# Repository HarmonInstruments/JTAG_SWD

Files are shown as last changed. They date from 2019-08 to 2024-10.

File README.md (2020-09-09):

# JTAG_SWD

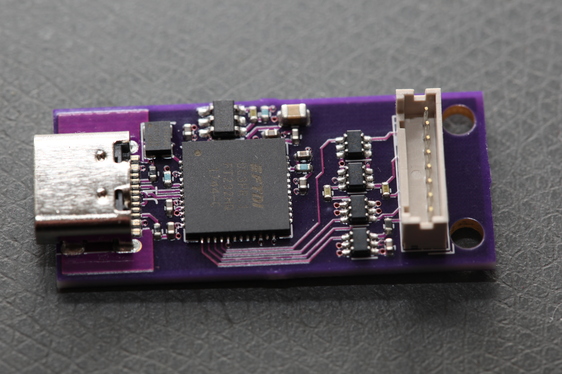
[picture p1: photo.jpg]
photo of PCB


## JTAG

Hirose DF3A-6P-2DS header

## Adapter Cables

###

Hirose DF3-6EP-2C 6 pin inline header

TC2030-MCP
TC2030-MCP-NL

## Pinout

|Pin |JTAG | Serial Wire | AVR |
|----|-----|---|-----|
| 1  | VCC | VCC | VCC |
| 2  | TCK | SWCLK | SCK |
| 3  | GND | GND | GND |
| 4  | TDO | SWDIO | MISO |
| 5  | NC  | jumper to 6 | NC |
| 6  | NC  | jumper to 5 | NC |
| 7  | TDI | SWDIO | MOSI |
| 8  | TMS | NC | RST |

## OpenOCD config for ECP5-12

```
interface ftdi
ftdi_channel 0
ftdi_vid_pid 0x0403 0x6014
ftdi_layout_init 0x0058 0x00fb
ftdi_layout_signal nTRST -data 0x0010
ftdi_layout_signal nSRST -oe 0x0020
adapter_khz 10000

telnet_port 4444
gdb_port 3333
transport select jtag
reset_config none

jtag newtap lfe5 tap -expected-id 0x21111043 -irlen 8 -irmask 0xFF -ircapture 0x5
init
scan_chain
svf -tap lfe5.tap -quiet -progress build/display_fpga.svf
shutdown
```

## OpenOCD config for XC7A15T
```
interface ftdi
ftdi_channel 0
ftdi_vid_pid 0x0403 0x6014
ftdi_layout_init 0x0058 0x00fb
ftdi_layout_signal nTRST -data 0x0010
ftdi_layout_signal nSRST -oe 0x0020
telnet_port 4444
gdb_port 3333
transport select jtag
reset_config none
jtag newtap artix7 tap -irlen 6 -ignore-version -expected-id 0x0362E093
pld device virtex2 artix7.tap
adapter_khz 10000
adapter_nsrst_delay 200
init
pld load 0 top.bit
virtex2 read_stat 0
shutdown
```

## OpenOCD for SWD STM32F4

swd.cfg
```
source [find openocd.cfg]
flash info 0
flash write_image erase digital.elf
reset run
exit
```

openocd.cfg
```
interface ftdi
transport select swd
ftdi_channel 0
ftdi_vid_pid 0x0403 0x6014
ftdi_layout_init 0x0058 0x00fb
ftdi_layout_signal SWD_EN -data 0x0200
adapter_khz 1000
telnet_port 4444
gdb_port 3333
reset_config none
source [find target/stm32f4x.cfg]
init
reset halt
sleep 100
```

## AVRDude

```
avrdude -c c232hm -P USB -p m32u4 -v -b 500000
```

Higher baud rates failed.

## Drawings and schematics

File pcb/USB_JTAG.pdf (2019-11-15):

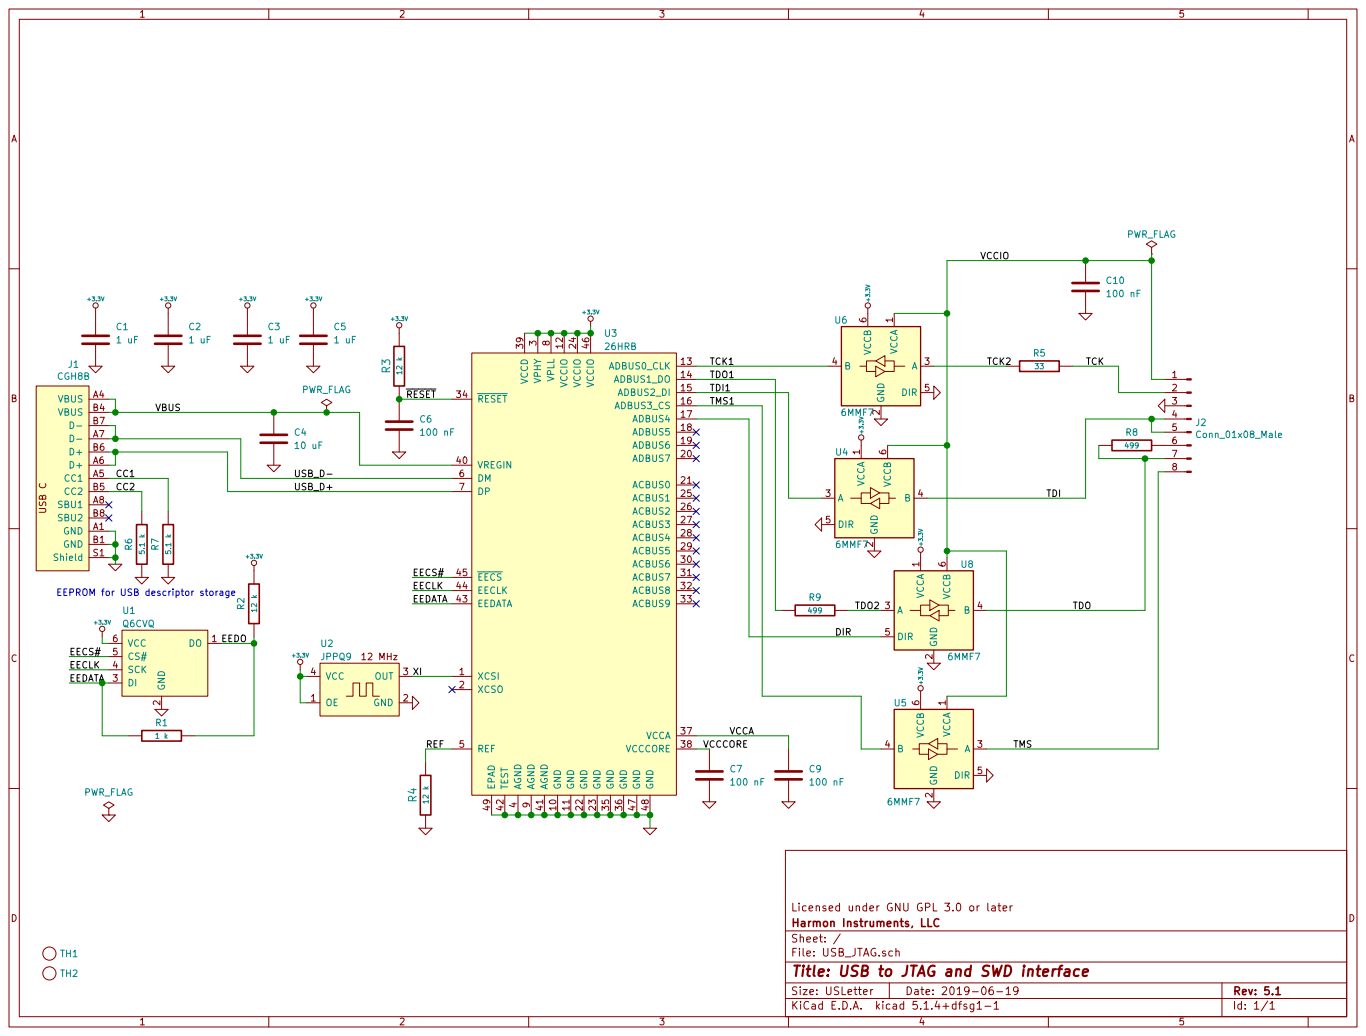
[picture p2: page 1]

3 ACBUS6 30 ACBUS7 31 ACBUS8 32 ACBUS9 33 RESET 34 GND 35 GND 36 VCCA 37 VCCCORE 38 VCCD 39 AGND

4 VREGIN 40 AGND 41 TEST 42 EEDATA 43 EECLK 44 EECS 45 VCCIO 46 GND 47 GND 48 EPAD 49 REF 5 DM 6 DP 7 VPLL

EEPROM for USB descriptor storage

2 DI 3 SCK 4 CS# 5 VCC 6 U1 Q6CVQ

File: USB_JTAG.sch Sheet: / Harmon Instruments, LLC

Id: 1/1 Title: USB to JTAG and SWD interface

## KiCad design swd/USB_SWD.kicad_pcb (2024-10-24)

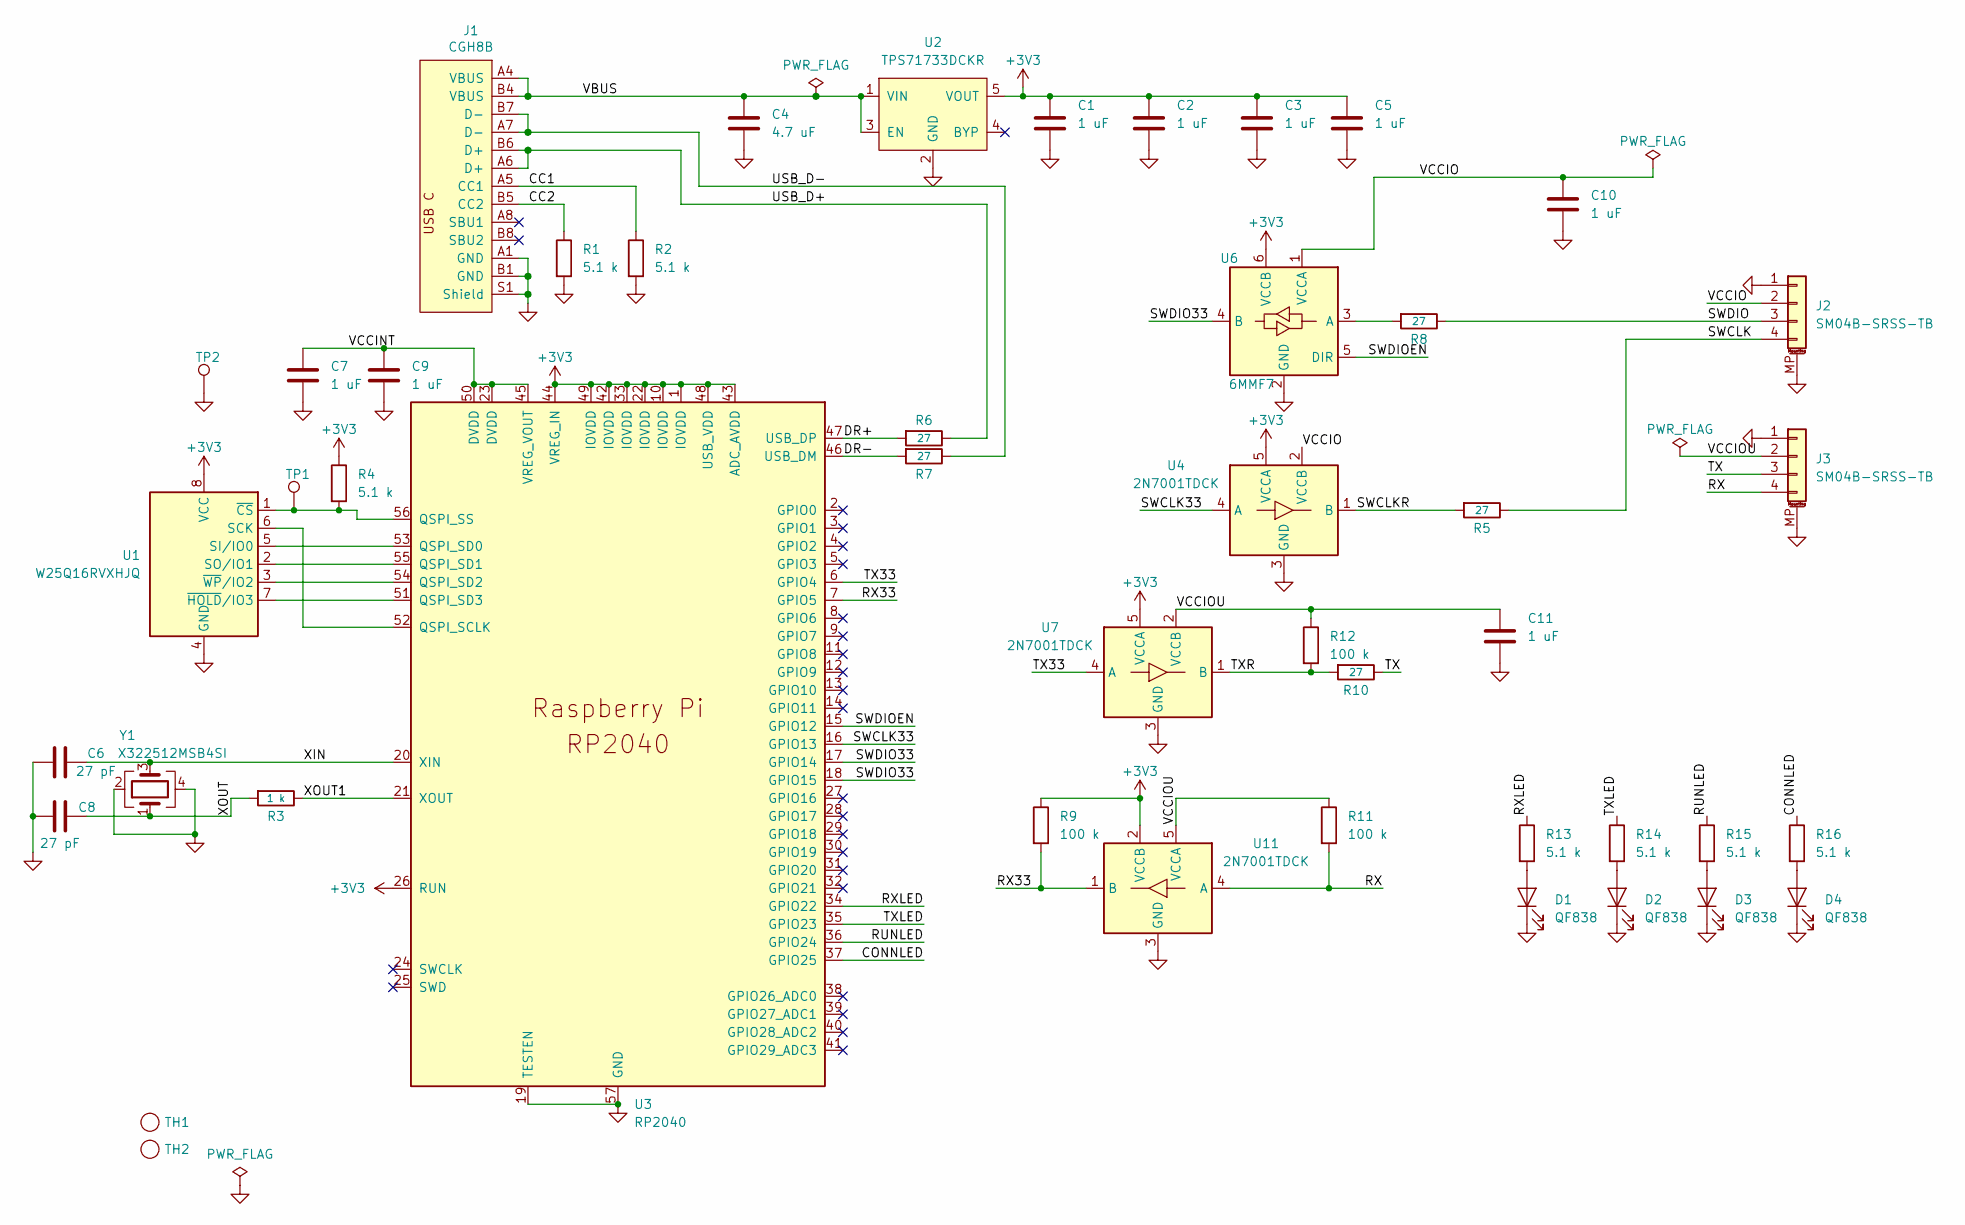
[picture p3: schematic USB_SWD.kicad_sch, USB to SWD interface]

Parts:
C1, C2, C3, C5, C7, C9, C10, C11: 1 uF; C_0402_1005Metric
C4: 4.7 uF; C_0603_1608Metric
C6, C8: 27 pF; C_0402_1005Metric
D1, D2, D3, D4: QF838; LED_0603_1608Metric
J1: CGH8B; USB_C_Receptacle_HRO_TYPE-C-31-M-12
J2, J3: SM04B-SRSS-TB; JST_SH_SM04B-SRSS-TB_1x04-1MP_P1.00mm_Horizontal
R1, R2, R4, R13, R14, R15, R16: 5.1 k; R_0402_1005Metric
R3: 1 k; R_0402_1005Metric
R5, R6, R7, R8, R10: 27; R_0402_1005Metric
R9, R11, R12: 100 k; R_0402_1005Metric
TH1, TH2: tooling_hole; tooling_hole_2.55
TP1, TP2: TestPoint; TestPoint_THTPad_1.5x1.5mm_Drill0.7mm
U1: W25Q16RVXHJQ; XSON-8-1EP_3x2mm_P0.5mm_EP0.2x1.6mm
U2: TPS71733DCKR; SOT-353_SC-70-5
U3: RP2040; QFN-56-RP2040
U4, U7, U11: 2N7001TDCK; SOT-353_SC-70-5
U6: 6MMF7; SOT-363_SC-70-6
Y1: X322512MSB4SI; Oscillator_SMD_SeikoEpson_SG8002CE-4Pin_3.2x2.5mm; LCSC C9002

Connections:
+3V3: C1.1, C2.1, C3.1, C5.1, R4.1, R9.1, U1.8 (VCC), U2.5 (VOUT), U3.1 (IOVDD), U3.10 (IOVDD), U3.22 (IOVDD), U3.26 (RUN), U3.33 (IOVDD), U3.42 (IOVDD), U3.43 (ADC_AVDD), U3.44 (VREG_IN), U3.48 (USB_VDD), U3.49 (IOVDD), U4.5 (VCCA), U6.6 (VCCB), U7.5 (VCCA), U11.2 (VCCB)
/CC1: J1.A5 (CC1), R2.1
/CC2: J1.B5 (CC2), R1.1
/CONNLED: R16.1, U3.37 (GPIO25)
/DR+: R6.2, U3.47 (USB_DP)
/DR-: R7.2, U3.46 (USB_DM)
/RUNLED: R15.1, U3.36 (GPIO24)
/RX: J3.4, R11.2, U11.4 (A)
/RX33: R9.2, U3.7 (GPIO5), U11.1 (B)
/RXLED: R13.1, U3.34 (GPIO22)
/SWCLK: J2.4, R5.1
/SWCLK33: U3.16 (GPIO13), U4.4 (A)
/SWCLKR: R5.2, U4.1 (B)
/SWDIO: J2.3, R8.1
/SWDIO33: U3.17 (GPIO14), U3.18 (GPIO15), U6.4 (B)
/SWDIOEN: U3.15 (GPIO12), U6.5 (DIR)
/TX: J3.3, R10.1
/TX33: U3.6 (GPIO4), U7.4 (A)
/TXLED: R14.1, U3.35 (GPIO23)
/TXR: R10.2, R12.2, U7.1 (B)
/USB_D+: J1.A6 (D+), J1.B6 (D+), R6.1
/USB_D-: J1.A7 (D-), J1.B7 (D-), R7.1
/VBUS: C4.1, J1.A4 (VBUS), J1.B4 (VBUS), U2.1 (VIN), U2.3 (EN)
/VCCINT: C7.1, C9.1, U3.23 (DVDD), U3.45 (VREG_VOUT), U3.50 (DVDD)
/VCCIO: C10.1, J2.2, U4.2 (VCCB), U6.1 (VCCA)
/VCCIOU: C11.1, J3.2, R11.1, R12.1, U7.2 (VCCB), U11.5 (VCCA)
/XIN: C6.1, U3.20 (XIN), Y1.3
/XOUT: C8.1, R3.2, Y1.1
/XOUT1: R3.1, U3.21 (XOUT)
GND: C1.2, C2.2, C3.2, C4.2, C5.2, C6.2, C7.2, C8.2, C9.2, C10.2, C11.2, D1.1 (K), D2.1 (K), D3.1 (K), D4.1 (K), J1.A1 (GND), J1.B1 (GND), J1.S1 (Shield), J2.1, J2.MP (MountPin), J3.1, J3.MP (MountPin), R1.2, R2.2, TP2.1, U1.4 (GND), U2.2 (GND), U3.19 (TESTEN), U3.57 (GND), U4.3 (GND), U6.2 (GND), U7.3 (GND), U11.3 (GND), Y1.2, Y1.4
unnamed: D1.2 (A), R13.2
unnamed: D2.2 (A), R14.2
unnamed: D3.2 (A), R15.2
unnamed: D4.2 (A), R16.2
unnamed: U1.6 (SCK), U3.52 (QSPI_SCLK)
unnamed: U1.5 (SI/IO0), U3.53 (QSPI_SD0)
unnamed: U1.2 (SO/IO1), U3.55 (QSPI_SD1)
unnamed: R4.2, TP1.1, U1.1 (~CS), U3.56 (QSPI_SS)
unnamed: U1.7 (~HOLD/IO3), U3.51 (QSPI_SD3)
unnamed: U1.3 (~WP/IO2), U3.54 (QSPI_SD2)
unnamed: R8.2, U6.3 (A)

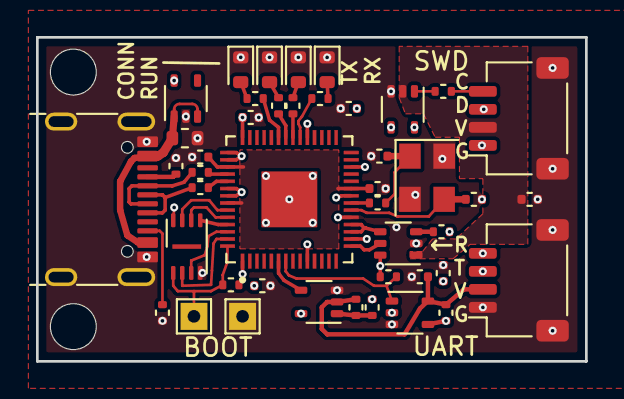
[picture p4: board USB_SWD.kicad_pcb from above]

Board: 6 copper layers, 30.5 x 18.0 mm, 46 parts (0 on the bottom side), 41 nets.

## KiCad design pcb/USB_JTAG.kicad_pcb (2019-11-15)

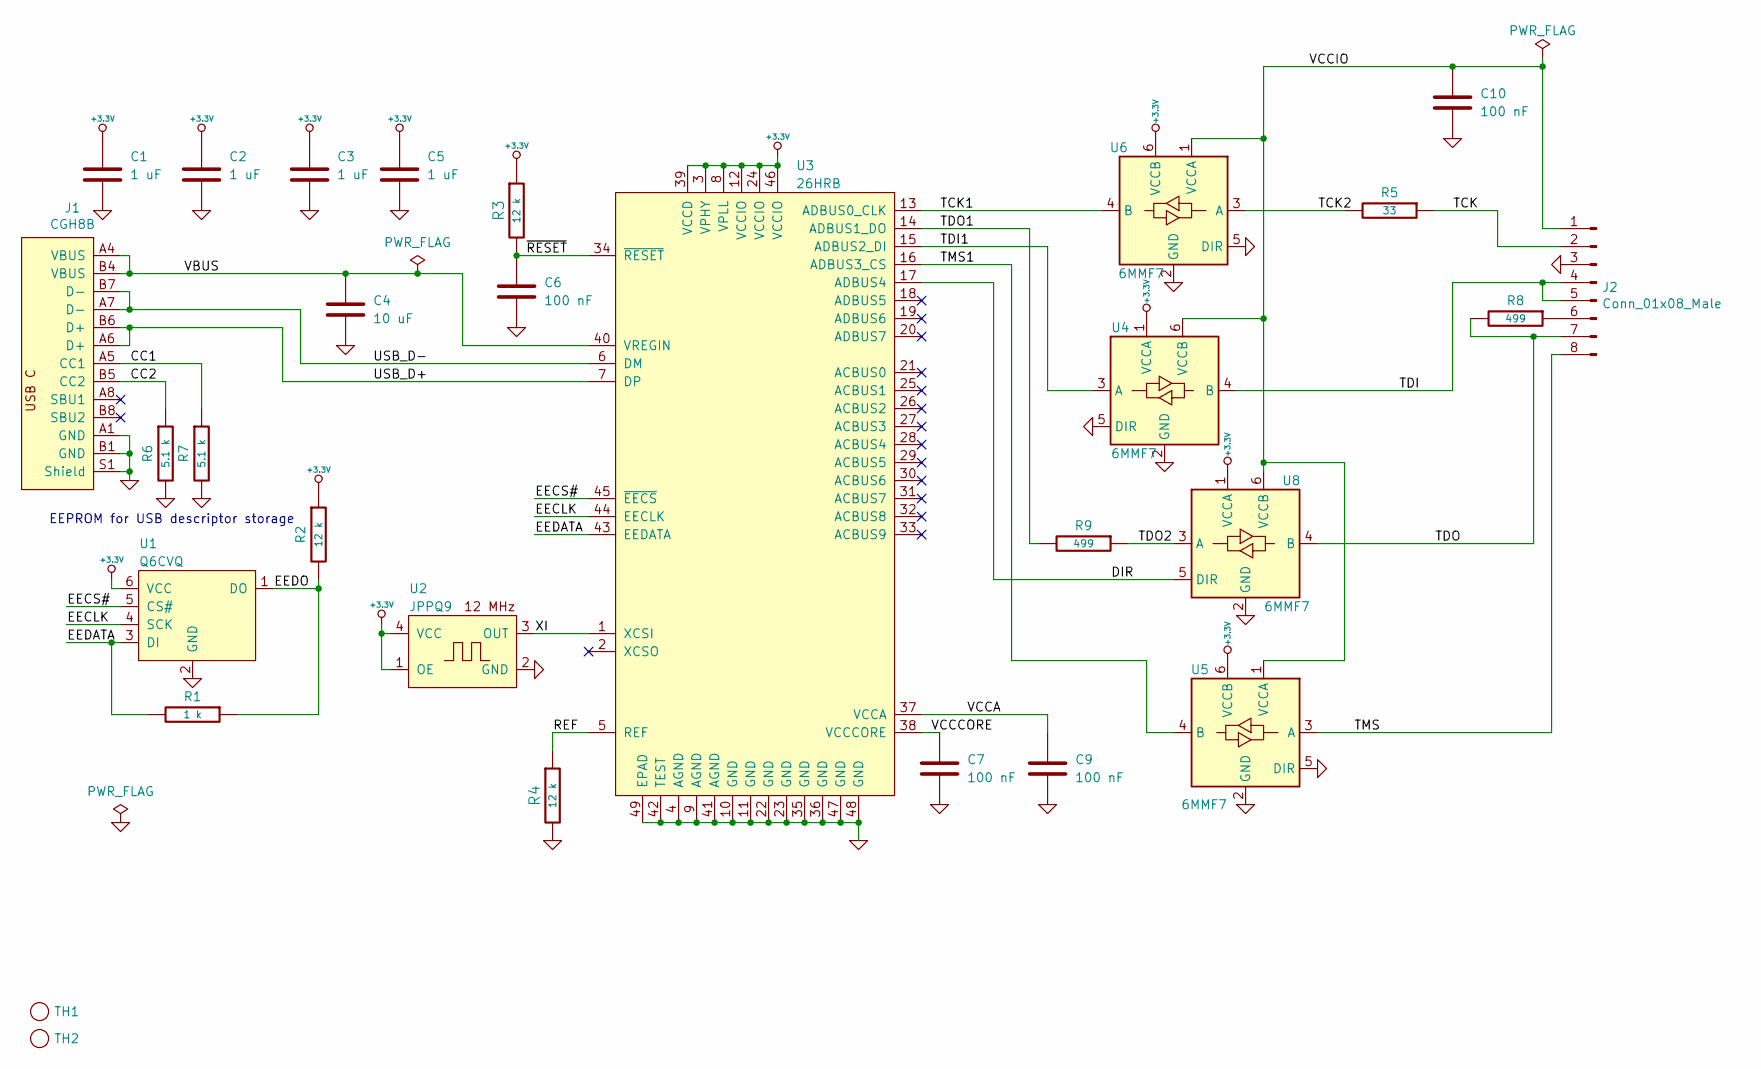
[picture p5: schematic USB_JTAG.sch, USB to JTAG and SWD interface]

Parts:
C1, C2, C3, C5: 1 uF; C_0402_1005Metric
C4: 10 uF; C_0805_2012Metric
C6, C7, C9, C10: 100 nF; C_0402_1005Metric
J1: CGH8B; USB_C_Receptacle_HRO_TYPE-C-31-M-12
J2: Conn_01x08_Male; Hirose_DF13-08P-1.25DSA_1x08_P1.25mm_Vertical
R1: 1 k; R_0402_1005Metric; Tolerance 10
R2, R3: 12 k; R_0402_1005Metric; Tolerance 10
R4: 12 k; R_0402_1005Metric; Tolerance 1
R5: 33; R_0402_1005Metric; Tolerance 10
R6, R7: 5.1 k; R_0402_1005Metric; Tolerance 10
R8, R9: 499; R_0402_1005Metric; Tolerance 10
TH1, TH2: tooling_hole; tooling_hole_2.55
U1: Q6CVQ; SOT-23-6
U2: JPPQ9; Oscillator_SMD_4Pin_2.5x2.0mm
U3: 26HRB; QFN-48-1EP_8x8mm_P0.5mm_EP6.2x6.2mm
U4, U5, U6, U8: 6MMF7; SOT-363_SC-70-6

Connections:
+3.3V: C1.1, C2.1, C3.1, C5.1, R2.1, R3.1, U1.6 (VCC), U2.1 (OE), U2.4 (VCC), U3.3 (VPHY), U3.8 (VPLL), U3.12 (VCCIO), U3.24 (VCCIO), U3.39 (VCCD), U3.46 (VCCIO), U4.1 (VCCA), U5.6 (VCCB), U6.6 (VCCB), U8.1 (VCCA)
/CC1: J1.A5 (CC1), R7.1
/CC2: J1.B5 (CC2), R6.1
/DIR: U3.17 (ADBUS4), U8.5 (DIR)
/EECLK: U1.4 (SCK), U3.44 (EECLK)
/EECS#: U1.5 (CS#), U3.45 (~EECS)
/EEDATA: R1.2, U1.3 (DI), U3.43 (EEDATA)
/EEDO: R1.1, R2.2, U1.1 (DO)
/REF: R4.1, U3.5 (REF)
/TCK: J2.2, R5.1
/TCK1: U3.13 (ADBUS0_CLK), U6.4 (B)
/TCK2: R5.2, U6.3 (A)
/TDI: J2.4, J2.5, U4.4 (B)
/TDI1: U3.15 (ADBUS2_DI), U4.3 (A)
/TDO: J2.7, R8.2, U8.4 (B)
/TDO1: R9.2, U3.14 (ADBUS1_DO)
/TDO2: R9.1, U8.3 (A)
/TMS: J2.8, U5.3 (A)
/TMS1: U3.16 (ADBUS3_CS), U5.4 (B)
/USB_D+: J1.A6 (D+), J1.B6 (D+), U3.7 (DP)
/USB_D-: J1.A7 (D-), J1.B7 (D-), U3.6 (DM)
/VBUS: C4.1, J1.A4 (VBUS), J1.B4 (VBUS), U3.40 (VREGIN)
/VCCA: C9.1, U3.37 (VCCA)
/VCCCORE: C7.1, U3.38 (VCCCORE)
/VCCIO: C10.1, J2.1, U4.6 (VCCB), U5.1 (VCCA), U6.1 (VCCA), U8.6 (VCCB)
/XI: U2.3 (OUT), U3.1 (XCSI)
/~RESET: C6.1, R3.2, U3.34 (~RESET)
GND: C1.2, C2.2, C3.2, C4.2, C5.2, C6.2, C7.2, C9.2, C10.2, J1.A1 (GND), J1.B1 (GND), J1.S1 (Shield), J2.3, R4.2, R6.2, R7.2, U1.2 (GND), U2.2 (GND), U3.4 (AGND), U3.9 (AGND), U3.10 (GND), U3.11 (GND), U3.22 (GND), U3.23 (GND), U3.35 (GND), U3.36 (GND), U3.41 (AGND), U3.42 (TEST), U3.47 (GND), U3.48 (GND), U3.49 (EPAD), U4.2 (GND), U4.5 (DIR), U5.2 (GND), U5.5 (DIR), U6.2 (GND), U6.5 (DIR), U8.2 (GND)
unnamed: J2.6, R8.1

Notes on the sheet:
EEPROM for USB descriptor storage

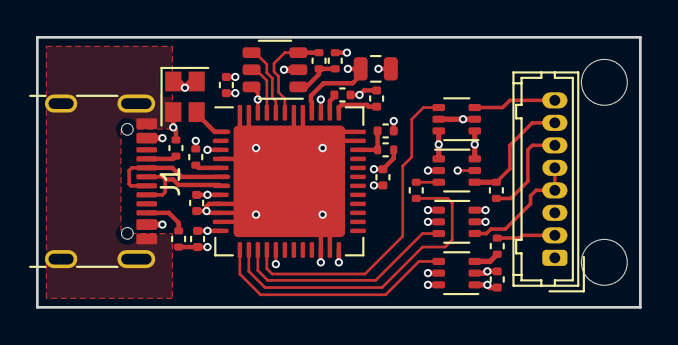
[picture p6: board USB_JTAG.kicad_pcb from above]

Board: 4 copper layers, 33.5 x 15.0 mm, 29 parts (0 on the bottom side), 29 nets.

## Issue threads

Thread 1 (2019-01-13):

FT232H footprint wrong

dlharmon, 2019-01-13:

dlharmon, 2019-06-20:
Fixed in Rev 5

Closed 2019-06-20.

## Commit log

2018-10-16 initial import
    [USB_JTAG_SWD.kicad_pcb, USB_JTAG_SWD.sch]
2019-06-01 fix FT232 FP
    [USB_JTAG.kicad_pcb, USB_JTAG.sch, USB_JTAG_SWD.kicad_pcb]
2019-06-20 fix TDI/TDO swap closes #2
    [USB_JTAG.kicad_pcb, USB_JTAG.sch]
2019-11-15 Fix net labels closes #3
    [USB_JTAG.kicad_pcb, USB_JTAG.sch]
2024-10-24 add SWD board
    [USB_SWD.kicad_pcb, USB_SWD.kicad_sch]

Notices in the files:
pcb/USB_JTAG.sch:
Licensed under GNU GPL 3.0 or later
